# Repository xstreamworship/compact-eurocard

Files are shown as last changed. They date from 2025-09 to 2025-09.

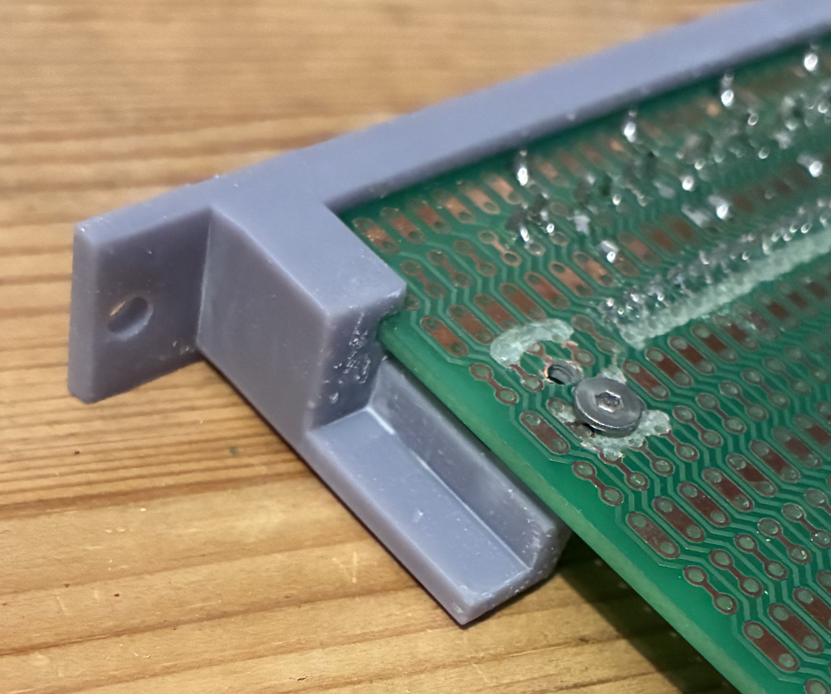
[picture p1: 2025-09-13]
diagrams-pictures/top-edge-showing-card-guide-clearance.jpeg

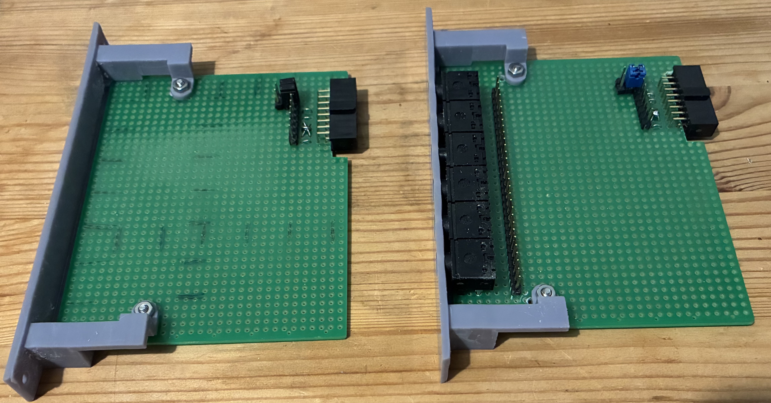
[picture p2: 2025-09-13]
diagrams-pictures/assembled-proto-cards.jpeg

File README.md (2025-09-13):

# compact-eurocard
Compact EuroCard (CEC) is an adaptation of EuroCard specifications (IEC-60297-3-101) intended for digital modular music synthesis as well as related and other control applications.  The distinguishing features are to use half depth 100mm by 80mm cards suitable for purpose built MCU and SoC based modules but to maintain compatibility with EuroRack.

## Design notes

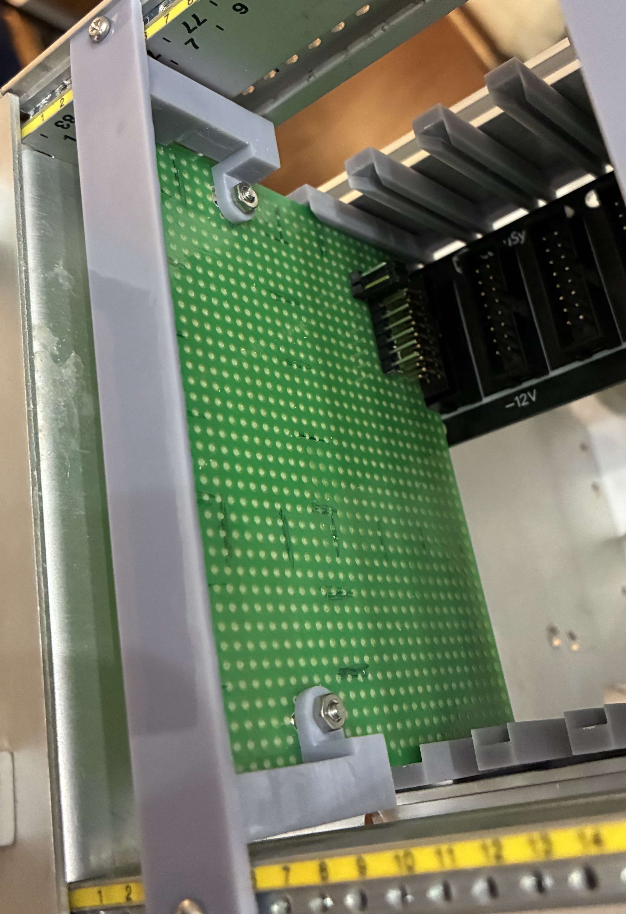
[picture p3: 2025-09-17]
diagrams-pictures/front-view-into-cage-5.jpeg

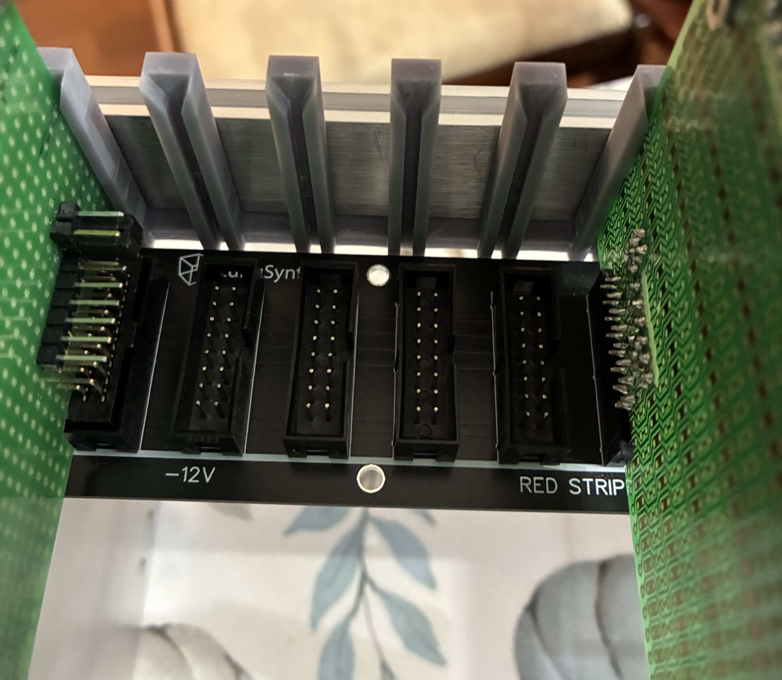
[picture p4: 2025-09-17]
diagrams-pictures/front-view-into-cage-3.jpeg

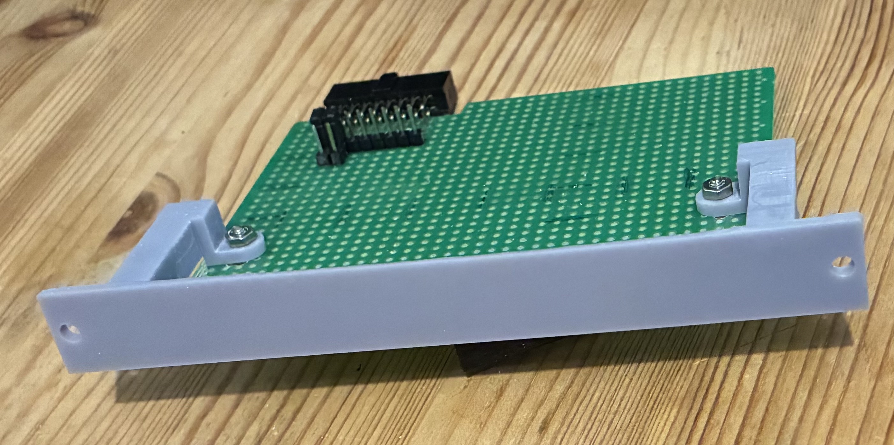
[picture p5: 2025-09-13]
diagrams-pictures/front-view-plain.jpeg

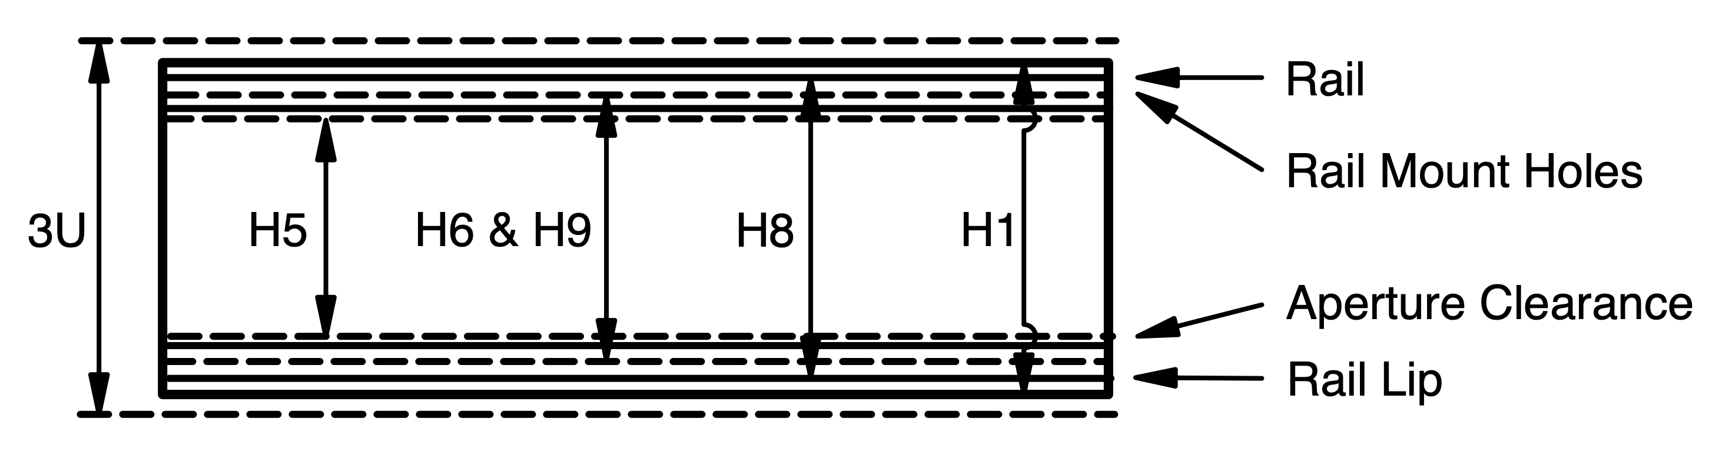
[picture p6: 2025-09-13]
diagrams-pictures/3ru-sub-cage.png

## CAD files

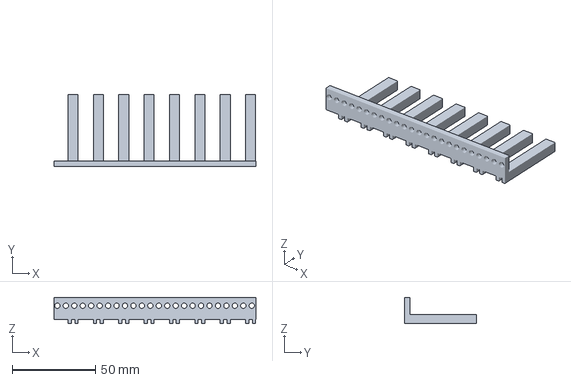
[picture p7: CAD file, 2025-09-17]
mechanical/3dprints/cec-3hp-8gang-cardguides-20250914/cec-3hp-8gang-cardguide-top-20250914.3mf
121.4 x 43.5 x 15.8 mm

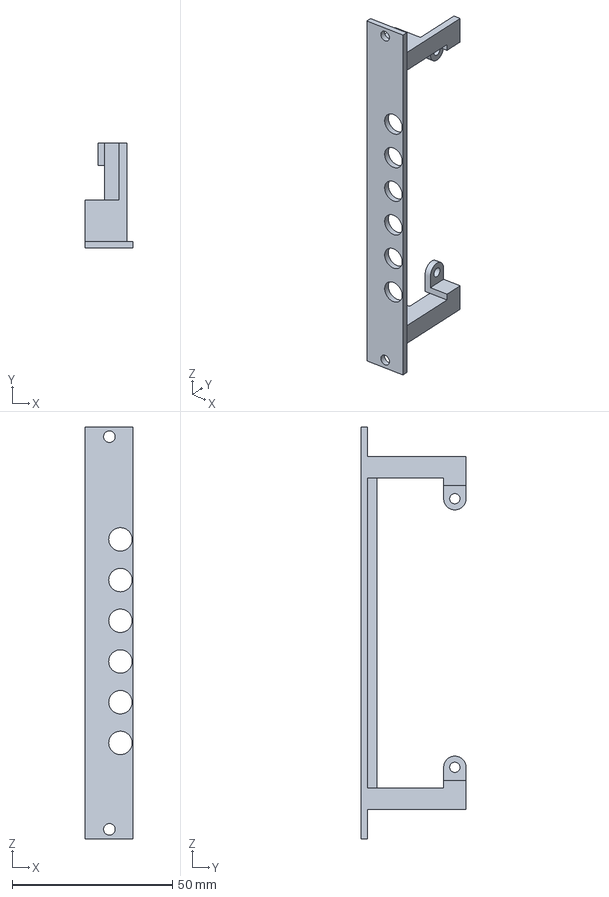
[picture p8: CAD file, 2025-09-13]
mechanical/3dprints/cec-6jackholes-20250908/cec-3hp-6jackholes-faceplate-with-brackets.3mf
15.1 x 32.8 x 128.6 mm

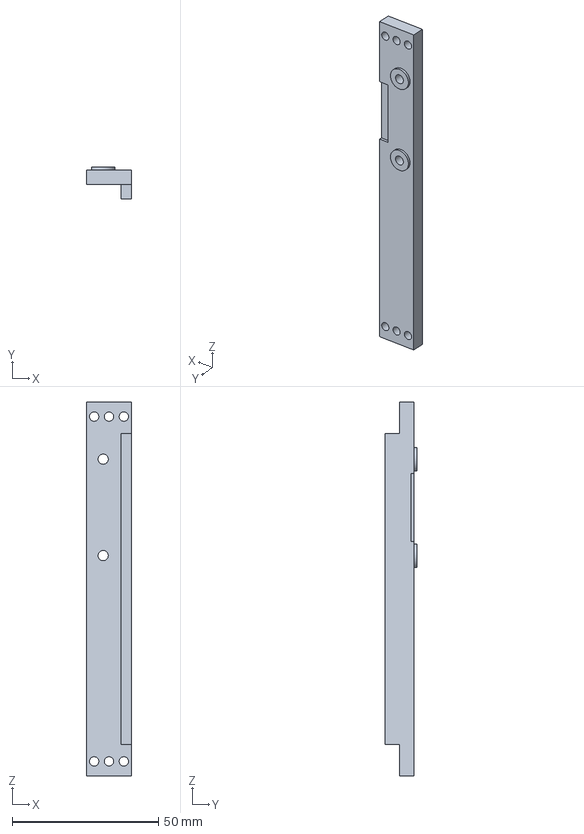
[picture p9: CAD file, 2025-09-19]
mechanical/3dprints/cec-backplane-beam-20250918/cec-backplane-beam-20250918-2.3mf
15.2 x 10.9 x 128.0 mm

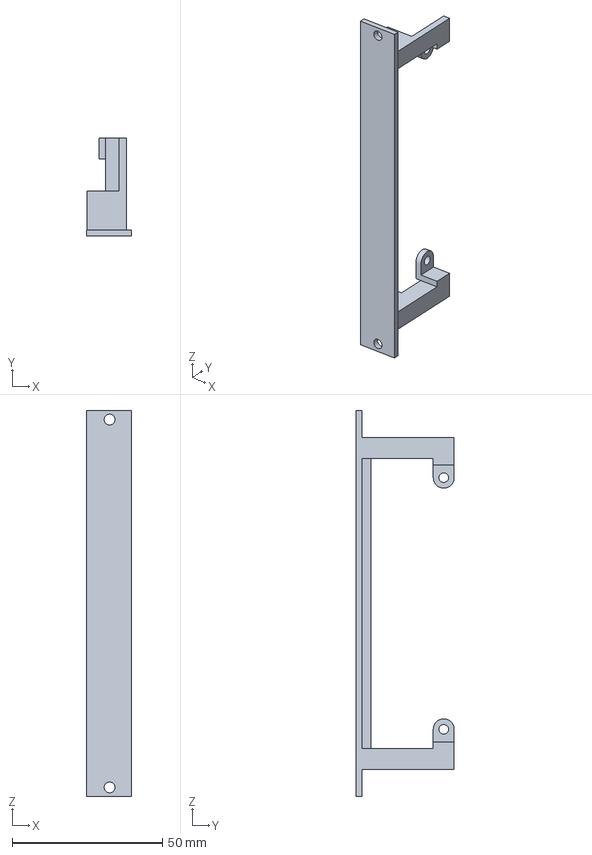
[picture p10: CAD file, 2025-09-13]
mechanical/3dprints/cec-plain-20250907/cec-3hp-plain-faceplate-with-brackets-20250907.3mf
14.8 x 32.8 x 128.6 mm

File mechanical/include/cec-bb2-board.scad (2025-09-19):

include <cec-common.scad>

///////////////////////////////////////////////////////
// Reference design based on BPS BB2 100mm by 80mm
// prototyping BusBoard.  Orientation is:
//   Height (long side of board) - Z axis - rows
//   Depth (short side of board) - Y axis - columns
//   Thickness (thickness of board) - X- axis
bb2Height = cecH10; // 100mm
bb2Depth = cecD3; // 80mm
bb2HoleSpacing = 2.54; // 2.54mm (breadboard spacing)
bb2NumRows = 38; // Rows of holes
bb2NumCols = 31; // Columns of holes
// Note: The margins on each side of the hole matrix
//       appear symmetrical top and bottom, and
//       front and rear.
bb2MarginTB = halfOf(bb2Height - ((bb2NumRows - 1) *
    bb2HoleSpacing)); // Margin at top and bottom.
bb2MarginFR = halfOf(bb2Depth - ((bb2NumCols - 1) *
    bb2HoleSpacing)); // Margin at front and rear.

echo(bb2MarginTB=bb2MarginTB, bb2MarginFR=bb2MarginFR);

// PCB mount hole locations are symmetrical top
// and bottom so we specify the top one as hole
// coordinates.  (Starting count from 1 not 0).
cecPCBHoleFrontOffset = 10; // Columns from front of PCB.
cecPCBHoleEdgeOffset = 3; // Rows from each side of PCB.


function bb2Col2YCoord(col) = bb2MarginFR + ((col -
    1) * bb2HoleSpacing); // Offset from front of PCB.
function bb2Row2ZCoord(row) = bb2MarginTB + ((row -
    1) * bb2HoleSpacing); // Offset from (top) side of PCB.

// These are computed, but can be overriden for a custom
// PCB based on a different format.
// Note: These are relative to the PCB top/bottom front
//       corners.
cecPCBHoleYBrd = bb2MarginFR + (cecPCBHoleFrontOffset -
    1) * bb2HoleSpacing; // Offset from front of PCB.
cecPCBHoleZBrd = bb2MarginTB + (cecPCBHoleEdgeOffset -
    1) * bb2HoleSpacing; // Offset from each side of PCB.

echo(cecPCBHoleYBrd=cecPCBHoleYBrd, cecPCBHoleZBrd=cecPCBHoleZBrd);

// Absolute coordinates.
cecPCBHoleYCoord = cecPCBSetback + cecPCBHoleYBrd;
cecPCBHoleZCoord = halfOf(bb2Height) - cecPCBHoleZBrd;

echo(cecPCBHoleYCoord=cecPCBHoleYCoord, cecPCBHoleZCoord=cecPCBHoleZCoord);

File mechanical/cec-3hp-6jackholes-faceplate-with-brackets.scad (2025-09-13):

// CEC 3HP Plain Faceplate With PCB Mount Brackets
// Copyright (C) 2025 Darcy L. Watkins

include <include/cec-3hp-faceplate-with-brackets.scad>

// Six jacks aligned with the following rows of the protoboard.
jackRows = [8, 13, 18, 23, 28, 33];
// Centerline of jack holes offset from the PCB component side.
jackOffset = 7.00;
// Jack diameter through the holes.
jackDia = 6.80;

cecWClearance = 0.2; // Need the extra bit of width.

module jackHole(row, offset)
{
    echo("Jack hole at ", row=row, offset=offset);
    // Down from top of PCB.
    jackZ = halfOf(cecH10) - bb2Row2ZCoord(row);
    // No special transform needed.
    jackX = offset;
    // Same offset as used for panel plate holes.
    jackY = -cecPanelThickness - cecHoleExt;

    translate([jackX, jackY, jackZ])
    rotate([-90,0,0])
    cylinder(h=cecPanelThickness + doubleOf(cecHoleExt),
        d=jackDia + cecClearance);
}

module cecPanel()
{
    // Panel plate, minus the holes, plus the ridge,
    // plus the two PCB spacers.
    union()
    {
        difference()
        {
            // Panel plate
            cecPanelPlate();
            // Mounting holes on each end
            cecPanelMountingHoles();
            // Jack holes
            for(row = jackRows)
                jackHole(row, jackOffset);
        }
        // Panel ridge
        cecPanelRidge();
        // Top PBC spacer
        cecPCBBracket();
        // Bottom PCB spacer
        mirror([0,0,1])
        cecPCBBracket();
    }
}

///////////////////////////////////////////////////////
// Main program to rendor the project.

// Make curves smoother
$fs = 0.25; // 3D printer layer thickness
$fa = 1;    // 1 degree increments minimum
$fn = 60;   // 60 items

cecPanel();

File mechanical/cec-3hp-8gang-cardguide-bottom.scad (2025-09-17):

// CEC 3HP 8-Ganged Card Guides (Bottom).
// Copyright (C) 2025 Darcy L. Watkins

include <include/cec-3hp-cardguide-with-mount.scad>

// Ganged card guides, with clearance trimmed off
// only at the end.
module cecCardGuides()
{
    gangs = 8;

    // Only trim it at the end of the gang.
    endTrimPlacement = [-cecPCBOffset + (gangs * cecWidth) -
        cecClearance,
        -cecRailMountThickness - halfOf(cecHoleExt),
        -cecRailMountHoleMinOffset - halfOf(cecHoleExt)];

    trimSize = [halfOf(cecClearance) + cecHoleExt,
        cecRailMountThickness + cecHoleExt,
        halfOf(cecH9prm - cecH10) +
        cecRailMountHoleMinOffset -
        halfOf(cecClearance) + cecHoleExt];

    difference()
    {
        union()
        {
            for(i=[0:gangs - 1])
            cecCardGuide(i * cecWidth);
        }

        // Trim at end.
        translate(endTrimPlacement)
        cube(trimSize);
        
    }
}

///////////////////////////////////////////////////////
// Main program to rendor the project.

// Make curves smoother
$fs = 0.25; // 3D printer layer thickness
$fa = 1;    // 1 degree increments minimum
$fn = 60;   // 60 items

mirror([1, 0, 0])
cecCardGuides();

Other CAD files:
mechanical/3dprints/cec-3hp-8gang-cardguides-20250914/cec-3hp-8gang-cardguide-bottom-20250914.3mf
mechanical/cec-3hp-8gang-cardguide-top.scad
mechanical/cec-3hp-plain-faceplate-with-brackets.scad
mechanical/cec-backplane-beam.scad
mechanical/include/cec-3hp-cardguide-with-mount.scad
mechanical/include/cec-3hp-faceplate-with-brackets.scad
mechanical/include/cec-common.scad
mechanical/include/cubu-synth-backplane.scad

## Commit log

2025-09-13 Add mechanicals for CEC faceplates with brackets
    These are after successful 3D print and fitting the 100mm by 80mm BB2 protoboards.
    One is with plain faceplate. The other has six jack holes in the faceplate.
    3D Print notes: The plain faceplate has tight fit clearance. If re-rendored,
    It should be the same as for the six hole faceplate. The six hole faceplate
    has less horizontal clearance (across the 3HP) because the jack holes are so
    close to the right edge. Note that these are prototypes.
    Also added drawings / diagrams used in the documentation.
    [cec-3hp-6jackholes-faceplate-with-brackets.3mf, cec-3hp-6jackholes-faceplate-with-brackets.scad, cec-3hp-faceplate-with-brackets.scad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]
2025-09-13 Add photos taken of 3D prints and assemblies.
2025-09-17 Add mechanicals for CEC 3HP 8-gang card guides
    Add more photos.
    [cec-3hp-8gang-cardguide-bottom-20250914.3mf, cec-3hp-8gang-cardguide-bottom.scad, cec-3hp-8gang-cardguide-top-20250914.3mf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]
2025-09-19 Add mechanicals for backplane PCB mount beam
    1. Reused one earlier function, so added optional offset args.
    2. Add the new SCAD files and generated files.
    [cec-3hp-cardguide-with-mount.scad, cec-backplane-beam-20250918-2.3mf, cec-backplane-beam.scad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]
